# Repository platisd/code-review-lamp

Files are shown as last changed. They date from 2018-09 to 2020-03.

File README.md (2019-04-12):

# Code Review Lamp
A colorful lamp to notify the developer team for pending code reviews.
Code Review Lamp

## What?
Code Review Lamp is a Neopixel-based, WiFi-enabled gadget that reminds developers to peer-review their colleagues' code. For each submission that has not been reviewed enough, it dims up and down at a color that is specific to the developer who is trying to introduce a new functionality to a project. The lamp stops shining once the code has either received enough reviews by the team, been merged or designated as *Work In Progress*. Currently, it is configured to work with [Gerrit](https://www.gerritcodereview.com/) (v.2.15) or GitHub, but it could be programmed to fetch data from different tools such as Jenkins, GitLab etc.

The gadget is comprised of an [ESP8266 microcontroller module](https://wiki.wemos.cc/products:d1:d1_mini) that connects wirelessly to the internet, as well as a [Neopixel ring](https://www.adafruit.com/product/1463) which displays various colors.

## Why?
At work, we are a fast-paced team that likes to commit (relatively) small and often. Every commit does not only have to pass the various tests that are being run by our Continuous Integration machinery, but also gets extensively code reviewed before allowed to be merged. Since we are *six* in total and our internal code of conduct dictates *two* positive approvals for each new submission, the lack of responsiveness when it comes to reviewing, can impede the development process and speed.

In an ideal world, developers would check their notification emails and would proceed on with reviewing their peer's code. However, as they are too absorbed by their ongoing work and perhaps slightly overwhelmed by the amount of emails they receive, these emails tend to be ignored. The common thought is that someone else in the team is going to review the code, but often no one does.

We have employed two different techniques so far to solve the problem. The first one includes shouting **CODE REVIEW** loudly and the second placing color-coded bean bags (I am not kidding :laughing:) on each others' desks. The third that hopes to rule them all is the Code Review Lamp!

Its advantage is that it continuously, and discretely, reminds developers that **the team** needs to review code and thus someone's work is being blocked as long as the lamp is shining. Additionally, they can see who is requesting the code review and how many reviews need to be conducted.

## How?
Reaping the benefits of the Code Review Lamp is simple for the development team member. They merely need to push code to Gerrit, add the group which includes all team members to the review and set the review to *Work in Progress* or *Ready for review* depending on whether they want the team to start or stop reviewing the code.

We have included a special user in our team's Gerrit group, representing the lamp, which is added along the team to each review. This user is being utilized by an ESP8266 microcontroller which connects to WiFi and [queries](https://gerrit-review.googlesource.com/Documentation/rest-api-changes.html) Gerrit for open reviews where this "lamp user" is a reviewer. Of course, it is not necessary to have a separate user for the lamp. Any team member's already existing account can be used and this way Code Review Lamps can be personalized. However, since we consider code reviews a *team activity* and the foundation of cross-functionality and knowledge-sharing, we have opted for the "team approach".

Next, for each review the user is assigned to, we determine how many reviews have been conducted and if they fall short of our agreed threshold, a color that corresponds to the *owner* of the review is displayed on the Neopixel ring.

### Software
The [Gerrit firmware](https://github.com/platisd/code-review-lamp/blob/master/firmware/gerrit_watcher/gerrit_watcher.ino), compatible with ESP8266 microcontrollers, utilizes the [Adafruit Neopixel](https://github.com/adafruit/Adafruit_NeoPixel) library to control the Neopixel ring. When using **Gerrit**, the JSON response is parsed manually, as existing solutions which would nicely serialize the whole stream would frequently cause heap overflow.

The [GitHub firmware](https://github.com/platisd/code-review-lamp/blob/master/firmware/github_watcher/github_watcher.ino) on the other hand does not parse the JSON response coming from **GitHub** itself directly. This is due to the API response being overly verbose for the ESP8266 microcontroller, which renders parsing it on the microcontroller infeasible. Instead, an external server has to be used which will process the data and merely send what colors should be displayed. An example of such a server, written in Python3, can be found [here](https://github.com/platisd/code-review-lamp/blob/master/firmware/github_watcher/github_reviews_watcher.py).

### Hardware
The gadget is rather simple to source and assemble. The only "custom" part is the [PCB](https://github.com/platisd/code-review-lamp/tree/master/hardware/gerrit_lamp) which merely connects the ESP8266 module with the Neopixel ring.

### Get started
After you have assembled the hardware, flash the firmware by following the steps below:
* If on Windows or Mac, download the [Serial to USB chip drivers](https://wiki.wemos.cc/downloads)
* Download and install the latest [Arduino IDE](https://www.arduino.cc/en/Main/Software) for your distribution
* Install the `Adafruit Neopixel` library
  * In Arduino IDE, click on `Sketch` :arrow_right: `Include Library` :arrow_right: `Manage Libraries`
  * Look for `Adafruit NeoPixel` and install the `Adafruit NeoPixel by adafruit`
* Install the ESP8266 SDK
  * In Arduino IDE, click on `File` :arrow_right: `Preferences` :arrow_right: `Additional Board Manager URLs`
  * Paste `http://arduino.esp8266.com/stable/package_esp8266com_index.json` and click `OK`
  * In Arduino IDE, click on `Tools` :arrow_right: `Board` :arrow_right: `Boards Manager`
  * Look for `esp8266` and install the `esp8266 by ESP8266 Community`
* Select the Wemos D1 Mini board
  * In Arduino IDE, click on `Tools` :arrow_right: `Board` :arrow_right: `LOLIN(WEMOS) D1 R2 & mini`
* Select the serial port your Code Review Lamp is connected to
  * In Arduino IDE, click on `Tools` :arrow_right: `Port`
* Copy & paste the [code](https://github.com/platisd/code-review-lamp/blob/master/firmware/gerrit_watcher/gerrit_watcher.ino) to your IDE
* Make the necessary adjustments for your own SSID, username etc
  * GitHub Token
    * Create a [personal access token](https://github.com/settings/tokens)
    * Give it all `repo` permissions if you want it to access your private repositories too, otherwise just `public_repo`
* Upload the firmware by clicking `Upload` (the right arrow button on the upper left corner of your IDE)

### How to use
* Commit your change to Gerrit or GitHub
* Add the group which includes the team as reviewers
  * A special "notification" user that will trigger the lamp should be part of the group
* ???
* Get your code reviewed faster!

## Components
* [Code Review Lamp PCB](https://www.pcbway.com/project/shareproject/W17435BSW42_code_review_lamp.html)
* [3D printed case](https://www.tinkercad.com/things/evNud1d8GYI)
* [16 RGB LED Neopixel Ring](https://www.adafruit.com/product/1463)
* [Wemos D1 Mini](https://wiki.wemos.cc/products:d1:d1_mini)
* 330Ohm resistor
* 470uF/16V capacitor
* M3x40mm screws (4)
* M3 nuts (4)
* Micro USB cable

## Media
* Article on [platis.solutions](https://platis.solutions/blog/2018/09/26/code-review-lamp/)
* [Demo video](https://www.youtube.com/watch?v=TPO2nQkfprY)

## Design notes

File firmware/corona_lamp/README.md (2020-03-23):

# Corona lamp
Corona lamp is a twist over the [Code Review lamp](https://github.com/platisd/code-review-lamp)
to raise awareness over the spread of the [CoViD-19](https://en.wikipedia.org/wiki/Coronavirus_disease_2019).

corona lamp

## What?

Corona lamp illuminates according to the growth rate of the CoViD-19 infections in the selected country,
over the past 2 weeks. Overall, the more red the lamp is, the higher the infection rate. When it gets
greener, it means that the growth rate of the disease is low or has even stopped.

There are **16** LEDs on the lamp, each illuminated for the disease's growth rate on that particular
day. The data are fetched wirelessly, via a ESP8266 microcontroller and their original source currently
is Center for Systems Science and Engineering
([CSSE](https://www.arcgis.com/apps/opsdashboard/index.html#/bda7594740fd40299423467b48e9ecf6)) at
Johns Hopkins University.

## Why?

Corona lamp, can be utilized to quickly monitor the progress of the country's efforts to halt
the disease, without being as *threatening* as graphs and sometimes misleading as plain numbers.

## How?

New data are fetched via the [covid-api](https://covid-api.quintessential.gr/) by
[Quintessential SFT](https://www.quintessential.gr/) every 12 hours. The source code for the service
can be found [here](https://github.com/Quintessential-SFT/Covid-19-API/).

Then, the growth rate for each day over the last (approximately) two weeks is calcutated and
assigned to a color.

### Dependencies

Fetch the following resources via the Arduino IDE library manager:

* [ArduinoJson](https://arduinojson.org/)
* [NTPClient](https://github.com/arduino-libraries/NTPClient)

### Personalize

To personalize the Corona Lamp for your country, simply change the `kCountry`
[value](https://github.com/platisd/code-review-lamp/blob/master/firmware/corona_lamp/corona_lamp.ino#L29)
accordingly. A list with the available countries can be found [here](https://covid-api.quintessential.gr/data/meta/countries).

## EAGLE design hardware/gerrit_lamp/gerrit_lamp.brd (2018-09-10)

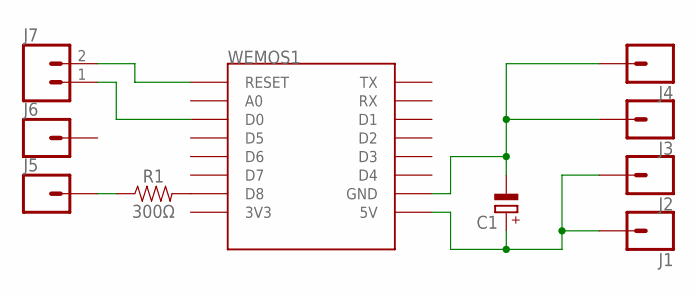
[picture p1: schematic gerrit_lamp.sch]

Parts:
C1: CPOL-EUE5-5; E5-5
J1, J2, J3, J4, J5, J6: CONN_01PTH_NO_SILK_KIT; 1X01NS_KIT
J7: CONN_02; 1X02
R1: 300Ω; AXIAL-0.3
WEMOS1: WEMOS-D1-MINI

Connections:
D0: J7.1, WEMOS1.D0
GND: C1.-, J3.1, J4.1, WEMOS1.GND
unnamed: R1.P$2 (2), WEMOS1.D8
unnamed: J5.1, R1.P$1 (1)
RST: J7.2, WEMOS1.RESET
VCC: C1.+, J1.1, J2.1, WEMOS1.5V

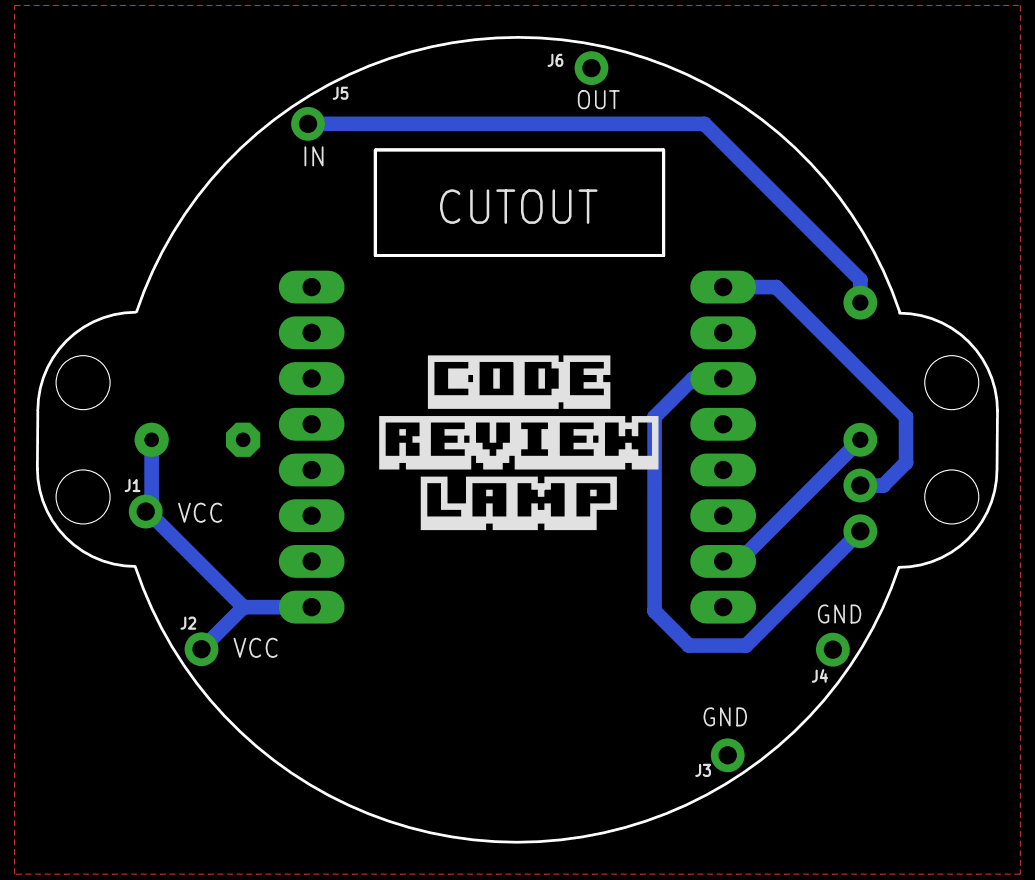
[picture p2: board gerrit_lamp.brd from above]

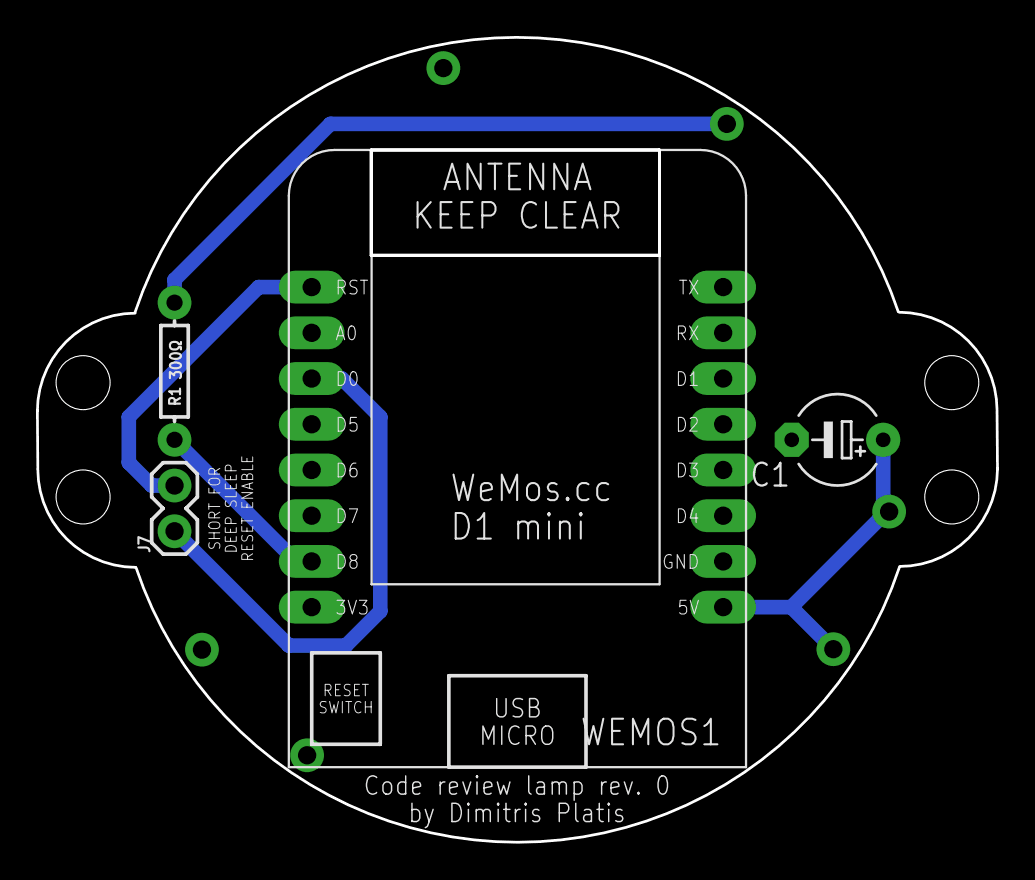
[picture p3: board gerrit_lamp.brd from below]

Board: 2 copper layers, 53.3 x 44.7 mm, 10 parts (4 on the bottom side), 6 nets.

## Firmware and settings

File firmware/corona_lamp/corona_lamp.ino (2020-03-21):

#include "Colors.h"
#include "Date.h"
#include "Optional.h"
#include "Utilities.h"
#include <Adafruit_NeoPixel.h>
#include <ArduinoJson.h>
#include <ESP8266HTTPClient.h>
#include <ESP8266WiFi.h>
#include <NTPClient.h>
#include <WiFiUdp.h>
#include <cassert>
#include <cstdint>
#include <ctime>
#include <vector>

using namespace corona_lamp;

const auto kSsid                    = "your-ssid";
const auto kPassword                = "your-password";
const auto kNeopixelPin             = 15;
const auto kNeopixelRingSize        = 16;
const auto kErrorBlinkInterval      = 250UL;
const auto kReconnectTimeout        = 100UL;
const auto kRetryConnectionInterval = 500UL;
const auto kConnectionRetries       = 20;
const auto kOneMinute               = 1000UL * 60UL;
const auto kWifiReconnectInterval   = 30000UL;

const auto kCountry               = "sweden";
const char kFingerprint[] PROGMEM = "07 62 08 46 01 4E 07 CB 68 AB 12 53 A8 5E 6F 7E D4 D3 4E 20";

const HSVColor MELLOW_YELLOW(40, 100, 100);

Adafruit_NeoPixel ring(kNeopixelRingSize, kNeopixelPin, NEO_GRB + NEO_KHZ800);
WiFiUDP ntpUDP;
NTPClient timeClient(ntpUDP);

/**
   Display an error pattern on the neopixels
   @param neopixels The neopixels to display the error
*/
void indicateError(Adafruit_NeoPixel& neopixels)
{
    // Blink red LEDs sequentially to indicate an error
    for (auto pixel = 0; pixel < neopixels.numPixels(); pixel++)
    {
        neopixels.setPixelColor(pixel, 200, 0, 0);
        neopixels.show();
        delay(kErrorBlinkInterval);
        neopixels.setPixelColor(pixel, 0, 0, 0);
        neopixels.show();
        delay(kErrorBlinkInterval);
    }
}

/**
   (Re)connects the module to WiFi
*/
void connectToWifi()
{
    // Set WiFi to station mode & disconnect from an AP if previously connected
    WiFi.mode(WIFI_STA);
    WiFi.disconnect();
    delay(kReconnectTimeout);

    // Try to connect to the internet
    WiFi.begin(kSsid, kPassword);
    auto attemptsLeft = kConnectionRetries;
    Serial.print("Connecting");
    while ((WiFi.status() != WL_CONNECTED) && (--attemptsLeft > 0))
    {
        delay(kRetryConnectionInterval); // Wait a bit before retrying
        Serial.print(".");
    }

    if (attemptsLeft <= 0)
    {
        Serial.println(" Connection error!");
        indicateError(ring);
    }
    else
    {
        Serial.println(" Connection success");
    }
}

std::vector<Date> getLatestDatePeriod(int days)
{
    static const auto secondsInDay = 86400UL;
    timeClient.update();
    // Get yesterday's data to ensure we are never too early to fetch data for the day
    const auto yesterday = timeClient.getEpochTime() - secondsInDay;
    std::vector<Date> period;

    for (auto i = days - 1; i >= 0; i--)
    {

        std::time_t t(yesterday - (i * secondsInDay));
        const auto now = std::localtime(&t);
        period.emplace_back(Date(now->tm_year + 1900, now->tm_mon + 1, now->tm_mday));
    }

    return period;
}

Optional<int> getInfectionsUntil(const Date& date, const char* country)
{
    WiFiClientSecure client;
    client.setFingerprint(kFingerprint);

    static const auto host = "covid-api.quintessential.gr";
    static const auto port = 443;

    if (!client.connect(host, port))
    {
        Serial.println("connection failed");
        return Nullopt;
    }

    static const String baseUrl = "/data/custom?";
    const String query          = baseUrl + String("country=") + String(country) + String("&date=") + String(date);

    const auto getRequest = String("GET ") + query + " HTTP/1.1\r\n" + "Host: " + host + "\r\n"
                            + "User-Agent: BuildFailureDetectorESP8266\r\n" + "Connection: close\r\n\r\n";
    client.print(getRequest);

    // Go through the headers before we can deserialize the JSON
    while (client.connected())
    {
        String line = client.readStringUntil('\n');
        if (line == "\r")
        {
            break;
        }
    }

    DynamicJsonDocument doc(600);
    deserializeJson(doc, client);
    const auto root               = doc.as<JsonArray>();
    const auto payload            = root[0];
    static const auto infectedKey = "Confirmed";

    Serial.print("Date: ");
    Serial.print(date);
    Serial.print("\t\t");

    if (!payload.containsKey(infectedKey))
    {
        Serial.println("No data");
        return Nullopt;
    }

    Optional<int> infections = payload[infectedKey].as<int>();
    Serial.println(infections.value());

    return infections;
}

std::vector<Optional<int>> getTotalInfectionsPerDayFor(const std::vector<Date>& period)
{
    std::vector<Optional<int>> totalInfectionsPerDay;

    for (const auto& date : period)
    {
        totalInfectionsPerDay.emplace_back(getInfectionsUntil(date, kCountry));
    }

    return totalInfectionsPerDay;
}

std::vector<Optional<float>> getInfectionGrowthRates(const std::vector<Optional<int>>& infections)
{
    std::vector<Optional<float>> infectionGrowthRates(infections.size() - 1);

    for (auto i = 1; i < infections.size(); i++)
    {
        const auto indexToFill = i - 1;
        if (!!infections.at(i))
        {
            if (!!infections.at(i - 1))
            {
                const auto currentInfection  = infections.at(i).value();
                const auto previousInfection = infections.at(i - 1).value();
                const auto infectionDelta    = currentInfection - previousInfection;
                const auto noGrowth          = infectionDelta == 0;
                const Optional<float> growthRate
                    = noGrowth ? 0.0f : static_cast<float>(infectionDelta) / static_cast<float>(previousInfection);
                infectionGrowthRates[indexToFill] = growthRate;
            }
            else
            {
                // If there are no previous data, assume an 100% growth rate
                infectionGrowthRates[indexToFill] = Optional<float>(1);
            }
        }
        else
        {
            infectionGrowthRates[indexToFill] = Nullopt;
        }
    }

    return infectionGrowthRates;
}

std::vector<HSVColor> getGrowthColors(const std::vector<Optional<float>>& growthRates)
{
    static const auto baseColor = MELLOW_YELLOW;
    std::vector<HSVColor> colors;

    for (const auto& growthRate : growthRates)
    {
        auto color = baseColor;
        if (!growthRate)
        {
            color = HSVColor(0, 0, 0);
        }
        else
        {
            static const auto okGrowthRate = 0.05f;
            const auto rate                = constrain(growthRate.value(), 0.0f, 1.0f);
            const auto hueDrift = rate <= okGrowthRate ? getMap<float>(rate, 0.0f, okGrowthRate, 100.0f, 60.0f)
                                                       : getMap<float>(rate, okGrowthRate, 1.0f, 20.0f, 0.0f);
            color.hue = hueDrift;
            Serial.print("Growth: ");
            Serial.print(growthRate.value());
        }
        Serial.print("\t\tHue: ");
        Serial.println(color.hue);
        colors.emplace_back(color);
    }

    return colors;
}

void showClockEffect(Adafruit_NeoPixel& neopixels, const std::vector<HSVColor>& colors)
{
    assert(neopixels.numPixels() <= colors.size());
    for (auto pixel = 0; pixel < neopixels.numPixels(); pixel++)
    {
        const auto color = colors.at(pixel).toRGB();
        neopixels.setPixelColor(pixel, color.red, color.green, color.blue);
        neopixels.show();
        delay(100);
    }
}

void dimDown(Adafruit_NeoPixel& neopixels, const std::vector<HSVColor>& colors)
{
    assert(neopixels.numPixels() <= colors.size());
    for (auto value = 100; value >= 0; value--)
    {
        for (auto pixel = 0; pixel < neopixels.numPixels(); pixel++)
        {
            const auto color = HSVColor(colors.at(pixel).hue, colors.at(pixel).saturation, value).toRGB();
            neopixels.setPixelColor(pixel, color.red, color.green, color.blue);
        }
        neopixels.show();
        delay(100);
    }
}

void dimUp(Adafruit_NeoPixel& neopixels, const std::vector<HSVColor>& colors)
{
    assert(neopixels.numPixels() <= colors.size());
    for (auto value = 0; value <= 100; value++)
    {
        for (auto pixel = 0; pixel < neopixels.numPixels(); pixel++)
        {
            const auto color = HSVColor(colors.at(pixel).hue, colors.at(pixel).saturation, value).toRGB();
            neopixels.setPixelColor(pixel, color.red, color.green, color.blue);
        }
        neopixels.show();
        delay(100);
    }
}

void setup()
{
    Serial.begin(115200);
    ring.begin();
    ring.show(); // Initialize all pixels to 'off'
    connectToWifi();
    timeClient.begin();
}

void loop()
{
    if (WiFi.status() != WL_CONNECTED)
    {
        connectToWifi();
        delay(kWifiReconnectInterval);
    }
    else
    {
        const auto daysToStudy          = kNeopixelRingSize + 1; // Number of pixels available + previous day
        const auto period               = getLatestDatePeriod(daysToStudy);
        const auto infectionsPerDay     = getTotalInfectionsPerDayFor(period);
        const auto infectionGrowthRates = getInfectionGrowthRates(infectionsPerDay);
        const auto colors               = getGrowthColors(infectionGrowthRates);
        for (auto hours = 0; hours < 12; hours++)
        {
            showClockEffect(ring, colors);
            for (auto minutes = 0; hours < 60; minutes++)
            {
                dimDown(ring, colors);
                dimUp(ring, colors);
                delay(kOneMinute);
            }
        }
    }
}

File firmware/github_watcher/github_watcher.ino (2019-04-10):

#include <vector>
#include <stdint.h>
#include <Adafruit_NeoPixel.h>
#include <ESP8266WiFi.h>
#include <ESP8266HTTPClient.h>

// Keep your project specific credentials in a non-version controlled
// `credentials.h` file and set the `NO_CREDENTIALS_HEADER` to false.
#define NO_CREDENTIALS_HEADER false
#if NO_CREDENTIALS_HEADER == true
const auto INTERNET_SSID = "your_ssid";
const auto PASSWORD = "your_password";
const auto GITHUB_USERNAME = "your_GITHUB_USERNAME";
const auto GITHUB_OAUTH2_TOKEN = "your_GITHUB_OAUTH2_TOKEN";
const auto INTERMEDIATE_SERVER = "http://your.flask.server/";
#else
#include "credentials.h"
#endif

enum class Effect {PULSE, RADAR, COOL_RADAR};
const auto MY_EFFECT = Effect::RADAR;

struct RGBColor {
  RGBColor(int r = 0, int g = 0, int b = 0) : red{r}, green{g}, blue{b} {}
  int red;
  int green;
  int blue;
};

struct HSVColor {
  /**
    @param h    Hue ranged          [0,360)
    @param s    Saturation ranged   [0,100]
    @param v    Value ranged        [0,100]
  */
  HSVColor(int h = 0, int s = 0, int v = 0) : hue{h}, saturation{s}, value{v} {}
  int hue;
  int saturation;
  int value;

  /**
    Converts HSV colors to RGB that can be used for Neopixels
    so that we can adjust the brightness of the colors.
    Code adapted from: https://stackoverflow.com/a/14733008

    @param hsv  The color in HSV format to convert
    @return     The equivalent color in RGB
  */
  RGBColor toRGB() const {
    // Scale the HSV values to the expected range
    auto rangedHue = map(hue, 0, 359, 0, 255);
    auto rangedSat = map(saturation, 0, 100, 0, 255);
    auto rangedVal = map(value, 0, 100, 0, 255);

    if (rangedSat == 0) {
      return {rangedVal, rangedVal, rangedVal};
    }

    auto region = rangedHue / 43;
    auto remainder = (rangedHue - (region * 43)) * 6;

    auto p = (rangedVal * (255 - rangedSat)) >> 8;
    auto q = (rangedVal * (255 - ((rangedSat * remainder) >> 8))) >> 8;
    auto t = (rangedVal * (255 - ((rangedSat * (255 - remainder)) >> 8))) >> 8;

    switch (region) {
      case 0:
        return {rangedVal, t, p};
      case 1:
        return {q, rangedVal, p};
      case 2:
        return {p, rangedVal, t};
      case 3:
        return {p, q, rangedVal};
      case 4:
        return {t, p, rangedVal};
      default:
        return {rangedVal, p, q};
    }
  }
};

const auto NEOPIXEL_PIN = 15;
const auto NEOPIXEL_RING_SIZE = 16;
const auto DIM_WINDOW = 10000UL;
const auto CHECK_FOR_REVIEWS_INTERVAL = 20000UL;
const auto ERROR_BLINK_INTERVAL = 250UL;
const auto WAIT_FOR_GITHUB_RESPONSE = 50UL;
const auto RECONNECT_TIMEOUT = 100UL;
const auto RETRY_CONNECTION_INTERVAL = 500UL;
const auto CONNECTION_RETRIES = 20;
const auto REQUEST_URL = INTERMEDIATE_SERVER + String(GITHUB_USERNAME) + "/" + String(GITHUB_OAUTH2_TOKEN);

const HSVColor KINDA_ORANGE (10, 100, 100);
const HSVColor MELLOW_YELLOW (30, 100, 100);
const HSVColor ALIEN_GREEN (100, 100, 100);
const HSVColor ALMOST_WHITE (293, 4, 70);
const HSVColor GREEK_BLUE (227, 100, 100);
const HSVColor GOTH_PURPLE (315, 100, 100);
const HSVColor BLOOD_RED (0, 100, 100);

Adafruit_NeoPixel ring(NEOPIXEL_RING_SIZE, NEOPIXEL_PIN, NEO_GRB + NEO_KHZ800);

/**
   Maps Gerrit user IDs to lamp colors, adapt accordingly.
   @param userId  Gerrit user ID
   @return The HSV color to match the specific user
*/
HSVColor toColor(const String& color) {
  if (color == "yellow") {
    return MELLOW_YELLOW;
  } else if (color == "green") {
    return ALIEN_GREEN;
  } else if (color == "purple") {
    return GOTH_PURPLE;
  } else if (color == "orange") {
    return KINDA_ORANGE;
  } else if (color == "red") {
    return BLOOD_RED;
  } else if (color == "blue") {
    return GREEK_BLUE;
  } else {
    return ALMOST_WHITE;
  }
}

/**
   Display an error pattern on the neopixels
   @param neopixels The neopixels to display the error
*/
void indicateError(Adafruit_NeoPixel& neopixels) {
  // Blink red LEDs sequentially to indicate an error
  for (auto pixel = 0; pixel < neopixels.numPixels(); pixel++) {
    neopixels.setPixelColor(pixel, 200, 0, 0);
    neopixels.show();
    delay(ERROR_BLINK_INTERVAL);
    neopixels.setPixelColor(pixel, 0, 0, 0);
    neopixels.show();
    delay(ERROR_BLINK_INTERVAL);
  }
}

/**
   (Re)connects the module to WiFi
*/
void connectToWifi() {
  // Set WiFi to station mode & disconnect from an AP if previously connected
  WiFi.mode(WIFI_STA);
  WiFi.disconnect();
  delay(RECONNECT_TIMEOUT);

  // Try to connect to the internet
  WiFi.begin(INTERNET_SSID, PASSWORD);
  auto attemptsLeft = CONNECTION_RETRIES;
  Serial.print("Connecting");
  while ((WiFi.status() != WL_CONNECTED) && (--attemptsLeft > 0)) {
    delay(RETRY_CONNECTION_INTERVAL); // Wait a bit before retrying
    Serial.print(".");
  }

  if (attemptsLeft <= 0) {
    Serial.println(" Connection error!");
    indicateError(ring);
  } else {
    Serial.println(" Connection success");
  }
}

/**
    Get all open reviews that our gerrit user has been assigned to,
    then figure out whether enough developers have code-reviewed
    each review. If this has not happened, return a color
    (mapped to a developer) for every un-reviewed review.
    Once a review has been reviewed adequately, remove ourselves
    from it.

    @return HSV colors for every unfinished code review
*/
std::vector<HSVColor> getColorsForUnfinishedReviews() {
  HTTPClient http;
  http.begin(REQUEST_URL);
  auto httpCode = http.GET();

  if (httpCode < 0 || httpCode != HTTP_CODE_OK) {
    Serial.printf("[%s] GET failed with code '%s'\r\n", __FUNCTION__, http.errorToString(httpCode).c_str());
    http.end();
    return {};
  }
  delay(WAIT_FOR_GITHUB_RESPONSE);

  auto documentLength = http.getSize();
  auto stream = http.getStream();

  std::vector<HSVColor> colors;
  if (http.connected() && (documentLength > 0 || documentLength == -1)) {
    while (stream.available()) {
      String color = stream.readStringUntil(',');
      colors.push_back(toColor(color));
    }
  }

  if (colors.empty()) {
    Serial.println("Warning - Colors not found!");
  }
  http.end();

  return colors;
}

/**
   Set the specified RGB color to all the pixels

   @param neopixels The neopixel structure to set color
   @param rgbColor  The RGB color to set the pixels
*/

void setAllPixelColor(Adafruit_NeoPixel& neopixels, RGBColor& rgbColor) {
  switch (MY_EFFECT) {
    case Effect::RADAR:
      setRadarEffect(neopixels, rgbColor);
      break;
    case Effect::PULSE:
      setPulseEffect(neopixels, rgbColor);
      break;
    case Effect::COOL_RADAR:
      setCoolRadarEffect(neopixels, rgbColor);
      break;
    default:
      setRadarEffect(neopixels, rgbColor);
      break;
  }
}
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

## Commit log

2018-09-04 Decrease heap memory usage
    Current setup has been tested with up to 7
    reviews. Serial is very shaky for some reason
    so using built in LED for debugging.
2018-09-08 Parse the stream directly without using ArduinoJSON
    Remove ArduinoJSON as the heap would often overflow in case there
    were too many JSON objects to handle. The new method does not
    completely rule out the problem (as vectors are used) but at least
    decreases a lot its likelihood.
    [gerrit_watcher.ino]
2018-09-09 Move arduino sketch into its own folder
2018-09-10 Add rev.0 hardware
    [gerrit_lamp.brd, gerrit_lamp.sch]
2018-09-19 Fix enough conducted reviews amount
    [gerrit_watcher.ino]
2018-09-20 Improve overall behavior
    * Reduce logging
    * Reduce operation interval time
    * Other small fixes and improvements
    [gerrit_watcher.ino]
2018-09-20 Do not remove user when enough reviews are conducted
    * Instead of removing the user once enough reviews have been
    completed (which would require the owner to re-add the user
    once a new patchset has been introduced) we rely on the owner
    toggling the "WorkInProgress" option which would make the change
    'invisible' to our user.
    * Remove blocking error indication
    [gerrit_watcher.ino]
2018-09-20 Replace map with switch-case
    For less heap memory consumption
    [gerrit_watcher.ino]
2018-09-20 Print return characters when using printf
    For better presentations in serial shells other than the
    Serial Monitor of Arduino IDE.
2018-09-26 Avoid pushing an empty owner id in case of GET error
    [gerrit_watcher.ino]
2018-09-26 Avoid undefined behavior of front() in possibly empty container
    [gerrit_watcher.ino]
2018-09-27 Add missing step
    Arduino IDE by default does not include the ESP8266 boards
2018-10-15 Adding skins for gerrit lamp: Pulse and Radar
    * Adding skins for geerit lamp: Pulse and Radar
    * Adding skins for gerrit lamp: Pulse and Radar
    * Added cool radar effect
    * Moving startingPixel out of global scope
    * Bug: Removed duplicated lines
    [gerrit_watcher.ino]
2018-10-18 Fix sketch aesthetics
    * Fix indentations
    * Fix unnecessary ussage of unsigned int
    [gerrit_watcher.ino]

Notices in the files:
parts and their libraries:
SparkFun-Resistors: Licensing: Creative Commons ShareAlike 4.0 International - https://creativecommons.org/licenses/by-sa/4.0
